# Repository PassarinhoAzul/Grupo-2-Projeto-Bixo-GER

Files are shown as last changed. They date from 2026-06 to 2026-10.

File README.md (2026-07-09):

# Projeto Bixo GER - Grupo 2 - Gênios da Bola

## Organizaçao das pastas:

``` 
|--- entrega1 (Entrega do Chassi)
         |--- modelos3d (modelos importados de fontes externas)
         |--- imagens (imagens usadas no README)
         |--- README (descrição da entrega)

|--- entrega2 (Entrega do Circuito)
         |--- código_teste (código para testar o esp32 e os motores)
         |--- esquemático (diagrama do circuito)
                    |---biblioteca_kicad (símbolos criados para o esquempatico)
                    |---arquivos_kicad (arquivo kicad do esquemático)
                    |---esquemático do projeto
         |--- imagens (imagens usadas no README)
         |--- README (descrição da entrega)
```

## Entregas
- Entrega 1: Chassi (17/06 às 18h00) 
- Entrega 2: Circuito (09/07 às 18h00)

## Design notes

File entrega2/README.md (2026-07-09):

# Entrega 02 - Projeto do Circuito

## Introdução

Primeiramente analisamos o datasheet de cada componente, para analisar qual seriam as conexões e placas a serem criadas para o projeto. Além disso, notamos a necessidade de alterar o suporte para o motor, já que ele não considerava a presença do encoder, que altera a altura do motor por causa da engrenagem. A partir disso, obtivemos alguns rascunhos. 

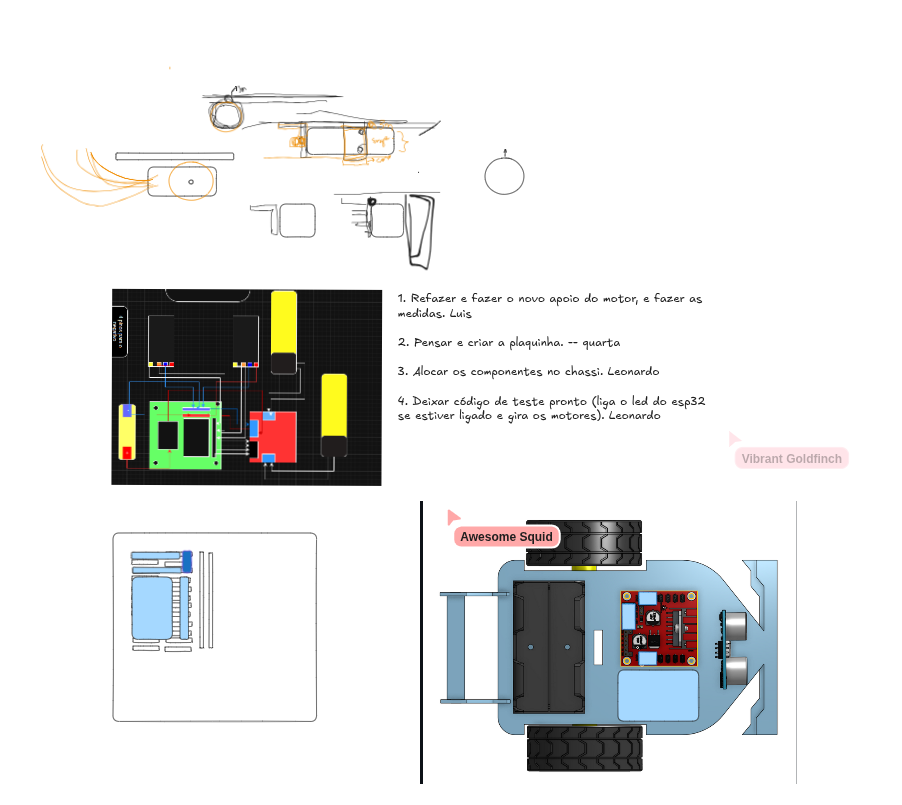
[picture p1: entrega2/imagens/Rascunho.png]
Rascunho


## Circuito

Fotos do esquemático:
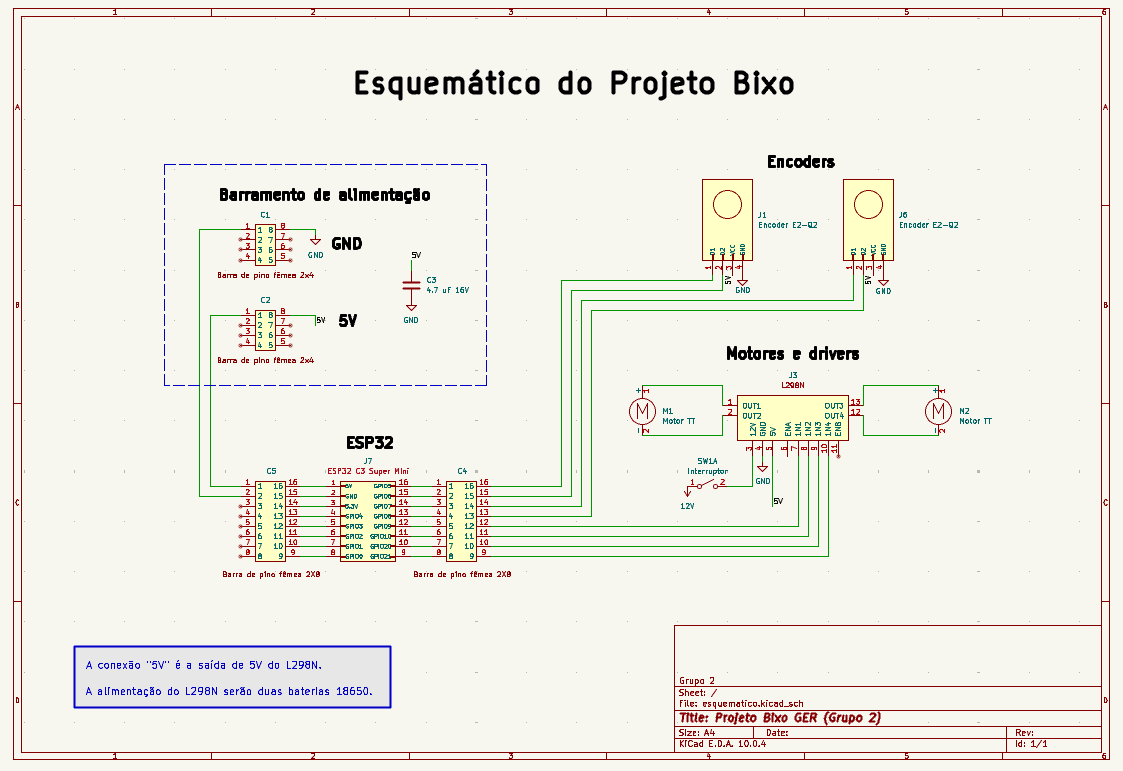
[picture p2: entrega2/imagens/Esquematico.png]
Esquemático


Fotos do circuito:
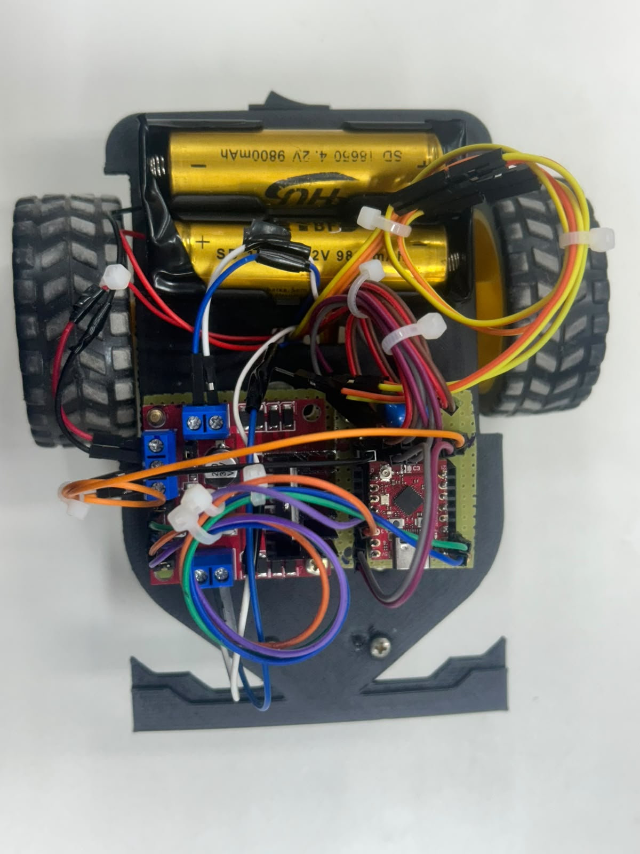
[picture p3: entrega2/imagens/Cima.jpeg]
Cima

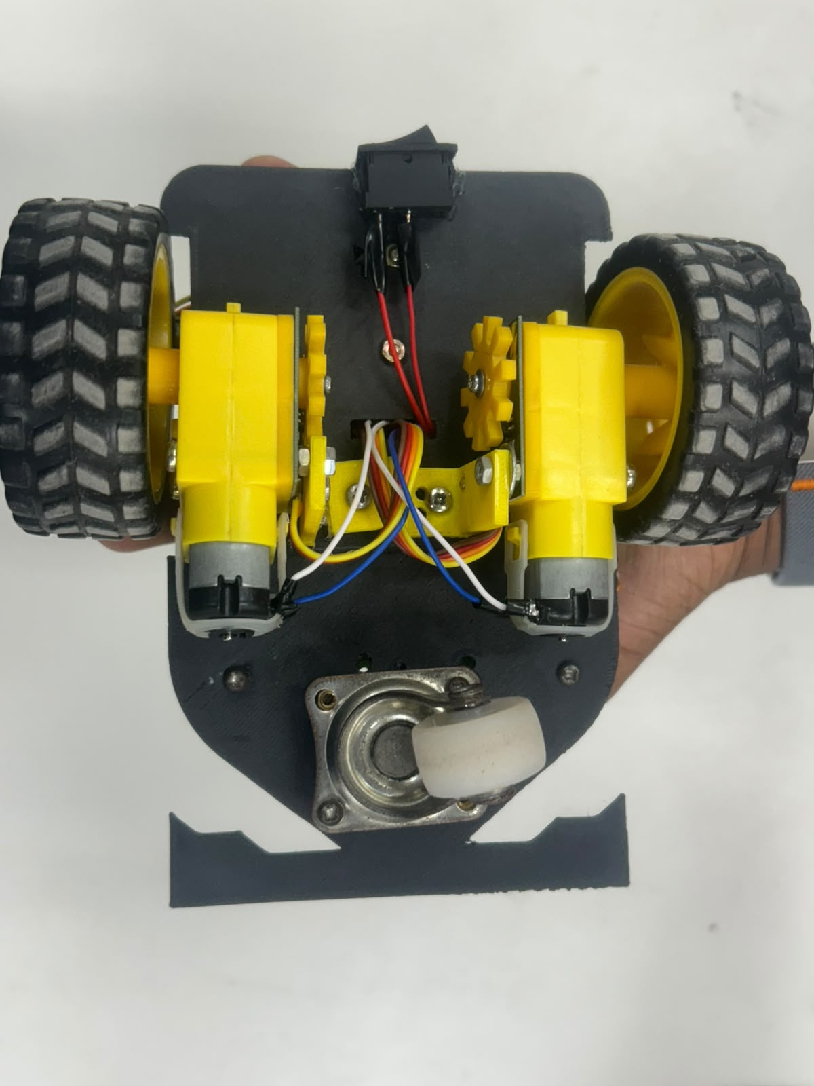
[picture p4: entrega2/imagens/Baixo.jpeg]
Baixo

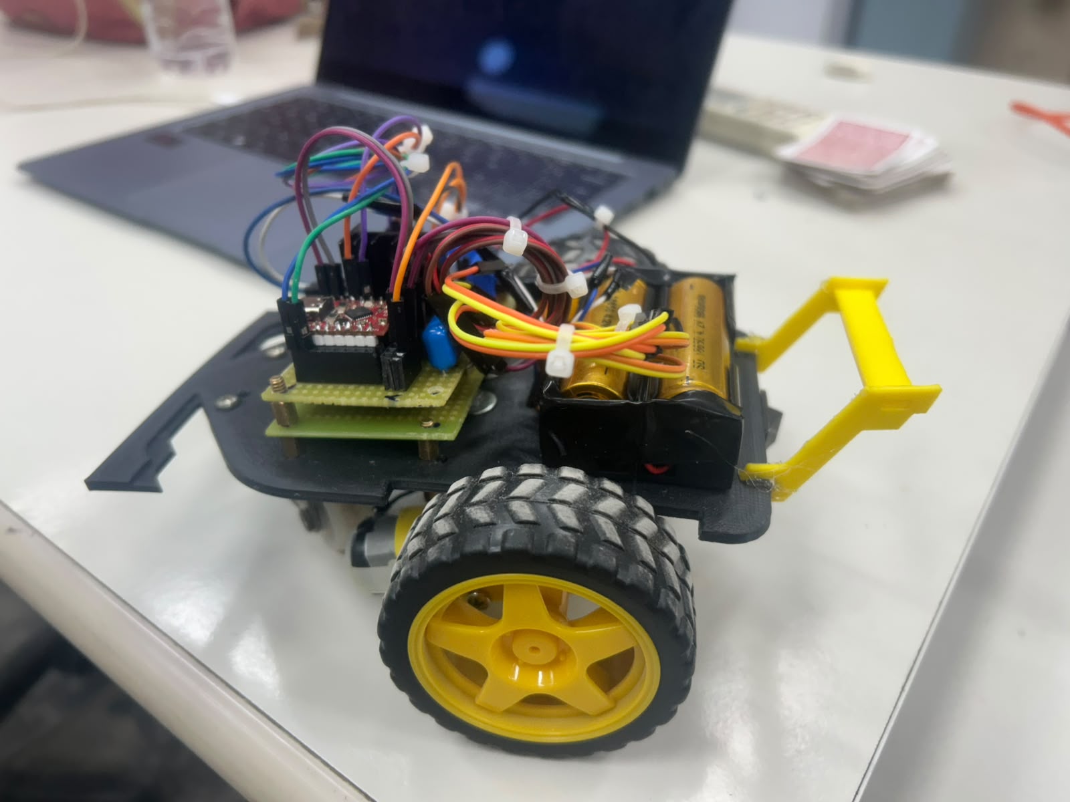
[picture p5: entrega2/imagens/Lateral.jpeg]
Lateral


***

### Alimentação:
A alimentação do circuito 'dividida em duas partes: 8V e 5V. 
- **8V:** alimentação da ponte H (L298N), feita através de duas pilhas 18650. As pilhas são colocadas em um suporte e a parte positiva desse conjunto é seccionado através de um interruptor que permite ligar ou desligar o robô.
- **5V:** alimentação do Esp32-C3 Super mini e dos Encoders. Ela advém do pino de +5V fornecido pela ponte H e do GND do robô, que são conectados em um barramento de alimentação (2x4 fêmea para cada). 

***

### Encaixe dos motores e encoders:
Para encaixar os motores e encoders, sofremos algumas dificuldades devido ao subdimensionamento dos suportes, já que não consideramos as engrenagens dos encoders. No entanto, conseguirmos resolver resolver esse problema utilizando uma sucata de impressão 3D, que possui uma altura adequada para ser encaixada entre os suportes e o chassi. Sendo assim, parafusamos esse conjunto. Outra dificuldade enfrentada foi a quebra de um dos suportes, que foi consertada utilizando um L em formato metálico, parafusando uma parte dele no suporte e a outra no chassi. Uma observação pertinente é que não foi possível imprimir novos suportes devido a falta de tempo e o não funcionamento da impressora no período.

***
### Encaixe das placas:
Para encaixar das placas, cortados uma placa ilhada em um tamanho adequado e montamos ela em cima do chassi, utilizando extensores, de tal forma que ela ficasse elevada. Isto é, pois haviam parafusos na parte inferior do espaço onde ficariam as placas. Após isso, montamos as placas no apoio com uso de porcas e parafusos, buscando fixar no mínimo 2 pontos de apoio. Além disso para o ESP32-C3 Super Mini, criamos uma placa com um barramento para todos os pinos do ESP, a fim de dar mias flexblidade no projeto, já que as conexões não permenantes permitem o teste de diferentes topologias.

***
### Procedimento:
Para os furos nas placas utilizamos a  furadeira de mão e de bancada, com pontas variando de 2mm a 4mm. Para fixar alguns componentes, como o aerofólio e o interruptor utilizamos cola quente. Para soldar os componentes, utilizamos a estação de solda, estanho e a fita de cobre. Por fim, para fixar os componentes, utilizamos porcas e parafusos, e para estruturas que necessitavam de muita pressão, inserimos aruelas entre as porca e parafusos para distribuir a pressão, não danificando o chassi.

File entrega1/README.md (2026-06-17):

# Entrega 01 - Projeto do Chassi

[Link do projeto no Onshape](https://cad.onshape.com/documents/1d821ed3f4f3fd0a0fea8587/w/eddb7fc55cb9cb03c94fa6ab/e/352dc380e6c08b1375bed07c)

## Procedimento 

A primeira coisa que fizemos foi medir os componentes que vamos utilizar no carrinho, sendo elas:
- ESP32-C3 Mini: 18mm x 22mm 4mm
- Sensor Ultrassônico HC-SR04: 45mm x 20mm x 15mm
- Ponte H L298N: 43mm x 43mm x 27
- Motor TT: 22mm x 70mm x 18mm
- Roda 65mm: 65mm x 27mm x 65mm
- Suporte para as pilhas: 75mm x 40mm x 20mm
- Roda Boba: 30mm x 30mm x ---

Após isso, fizemos uma reunião para debater as ideias iniciais para o modelo, buscando inspirações em carros de formula um e outros projetos semelhantes. O rascunho desenvolvido está representado na figura abaixo. 

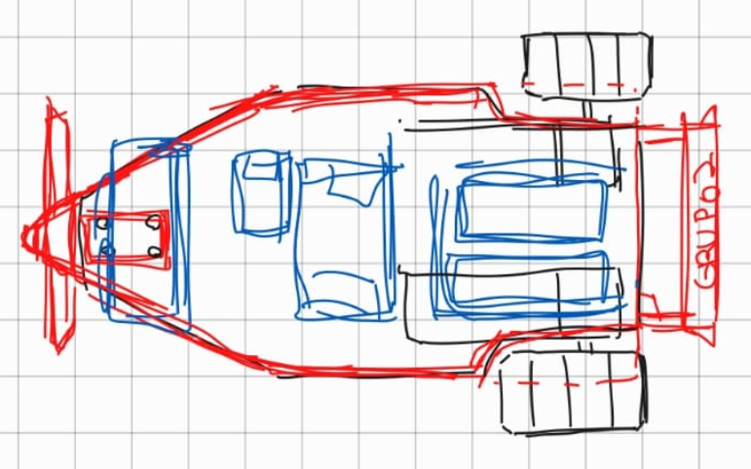
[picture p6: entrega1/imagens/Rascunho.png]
Rascunho


Durante a modelagem do projeto, baixamos modelos 3d dos componentes, obtidos no site ([3d Content Central](https://www.3dcontentcentral.com/Default.aspx)) para fazer testes com o modelo e verificar diferentes possibilidades para o posicionamento dos objetos no chassi.

## Modelo

Fotos do modelo com a simulação de componentes:

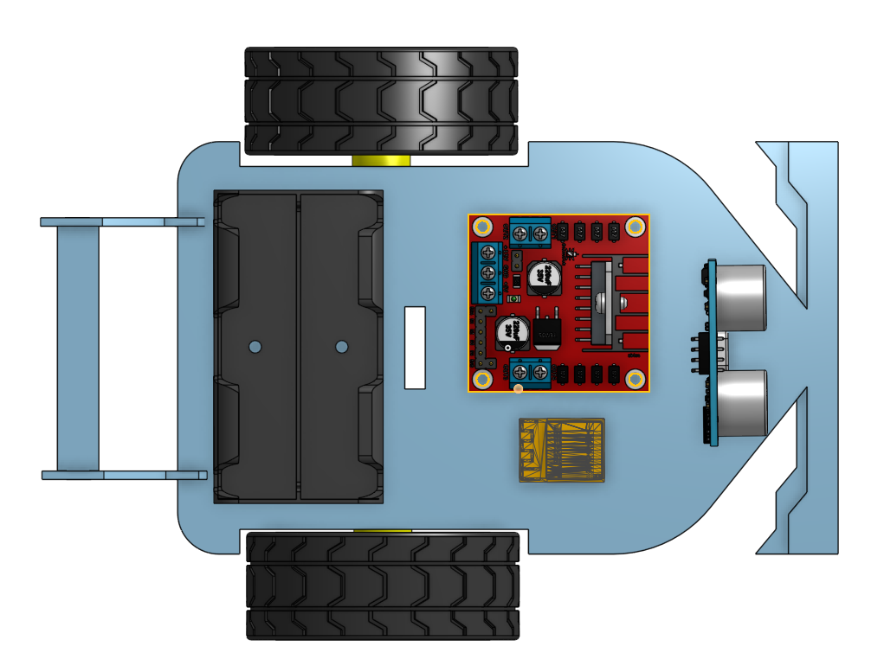
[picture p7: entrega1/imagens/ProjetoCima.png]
Cima

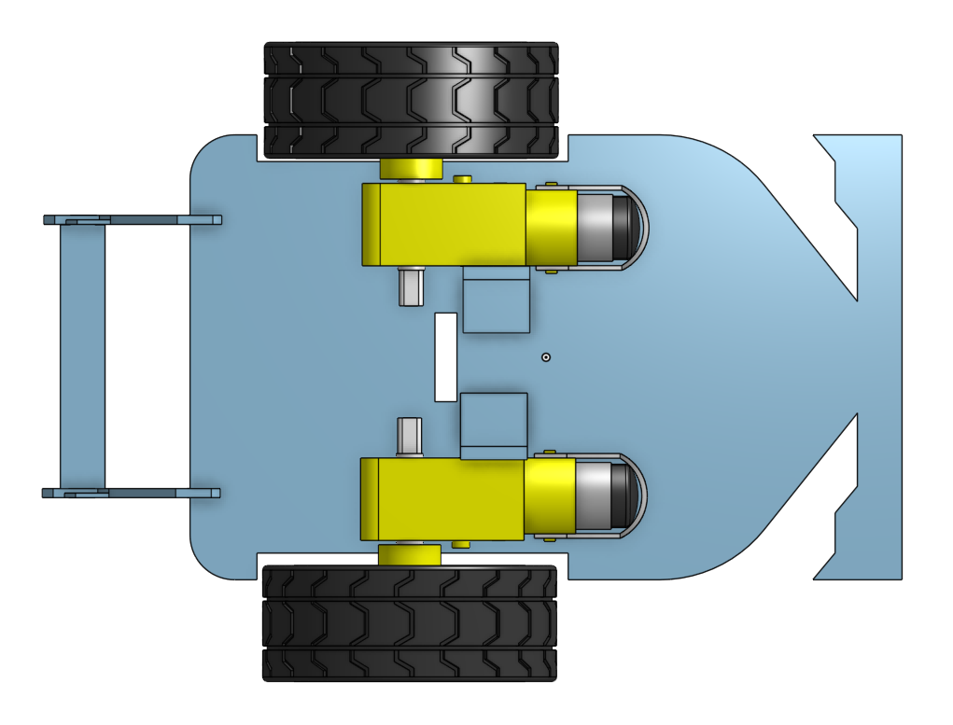
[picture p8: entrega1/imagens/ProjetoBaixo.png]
Baixo

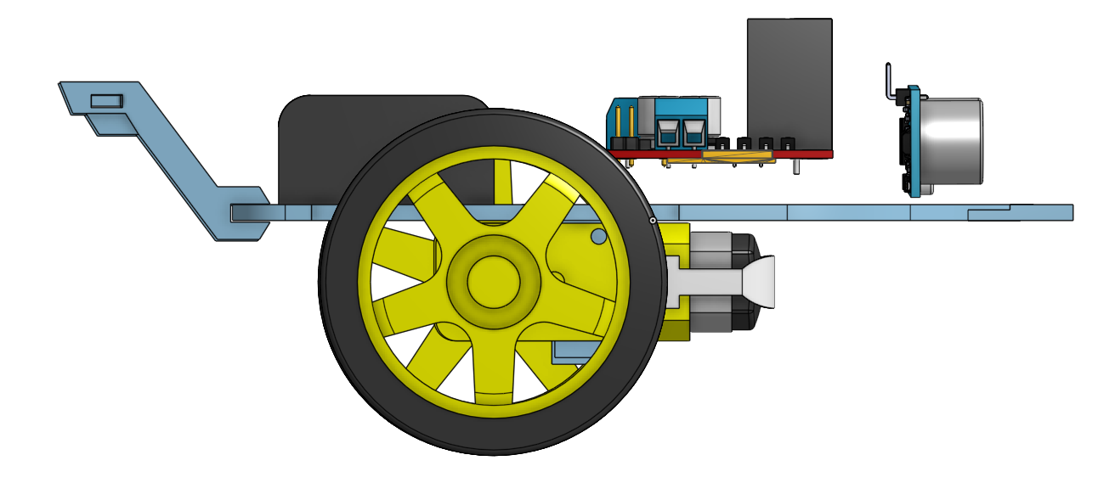
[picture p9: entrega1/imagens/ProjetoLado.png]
Lado


***

### Chassi:

As medidas do Chassi são de 100mm x 160m x 3m. Utilizamos essaas medidas baseada no encaixe dos componentes, com uma espessura adequada para suportar o peso de todos. Detalhando mais sobre o projeto, escolheu-se colocar os dois motores na parte de baixo e o restante dos componentes na parte de cima do chassi, reservando um espaço para um possível sensor ultrassônico. Além disso, o projeto possui um furo no centro para facilitar as conexões entre os componentes superiores e inferiores do carro. Por fim, os furos necessários para conectar os componentes ao chassi serão feitos utilizando uma furadeira, devido a facilidade e liberdade em compaação a criar furos diretamente no modelo das peças. Abaixo está uma imagem contendo o chassi.

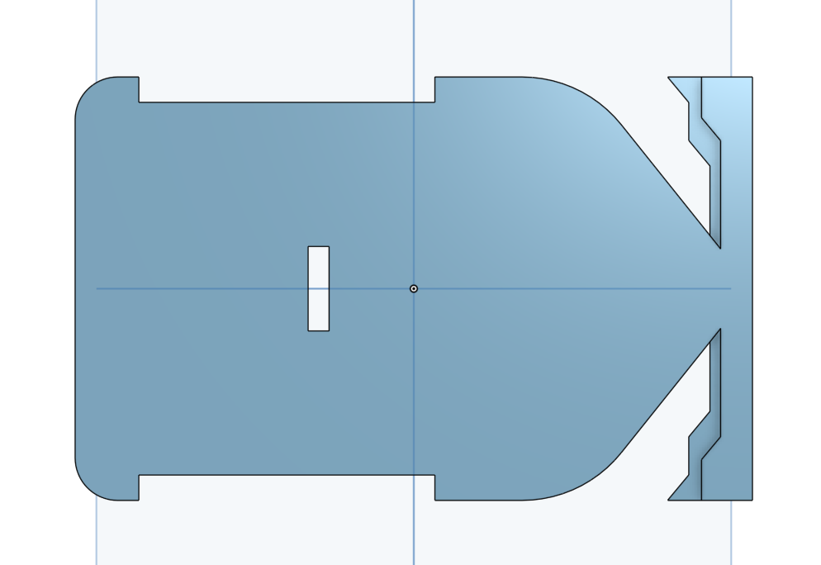
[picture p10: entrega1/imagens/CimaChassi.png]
Cima

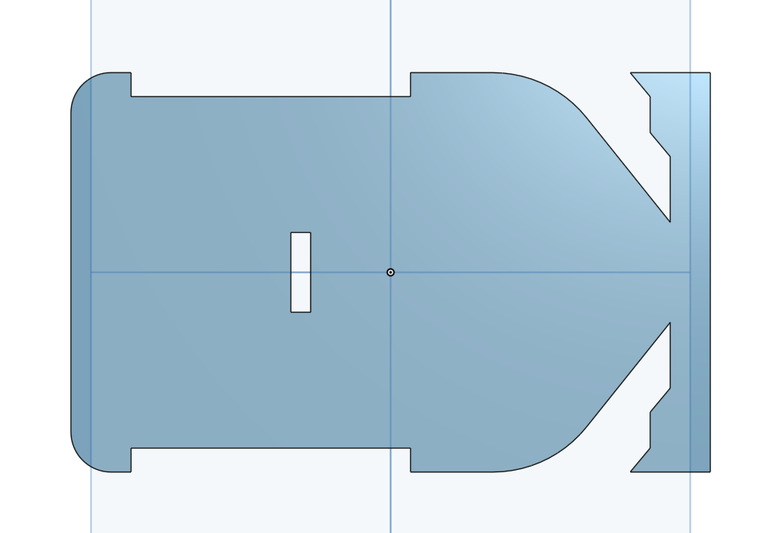
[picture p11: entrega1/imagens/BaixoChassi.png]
Baixo


***

### Aerofólio

O aerofólio é composto por duas partes: dois suportes laterais (30mm x 40mm x 3mm) e uma peça de encaixe horizontal (60mm x 10mm x 3mm). A tolerância para o encaixe de cada peça é de 0.5mm. Essa parte será encaixada e fortificada com cola no chassi. Abaixo está uma imagem contendo o aerofólio montado e cada peça individual. 

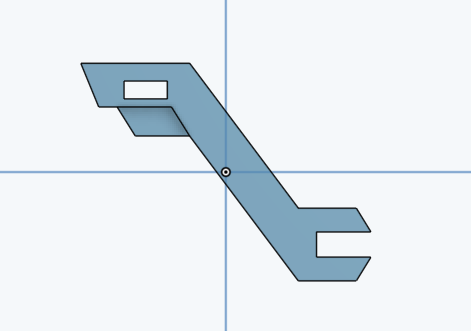
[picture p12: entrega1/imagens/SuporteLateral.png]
Suporte lateral

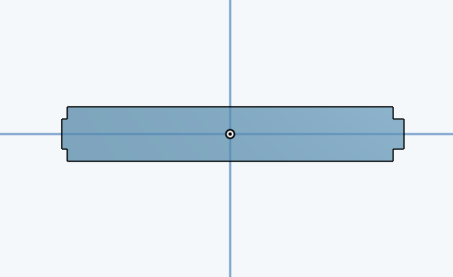
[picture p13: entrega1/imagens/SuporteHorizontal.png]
Suporte horizontal

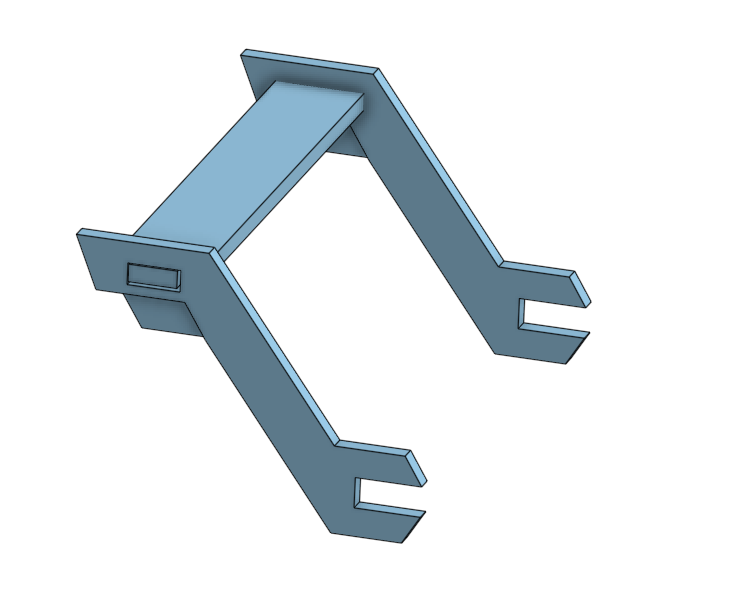
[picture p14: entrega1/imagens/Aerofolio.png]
Aerofólio montado


***

### Suportes:

Os suportes para os motores (localizados na parte debaixo do chassi) tem medida de (15mm x 15mm x 27mm). Os motores e os suporte serão parafusados (os furos serão feitos utilizando uma furadeira, devido a facilidade e liberdade em compaação a criar furos diretamente no modelo das peças) Abaixo está uma imagem do suporte. 

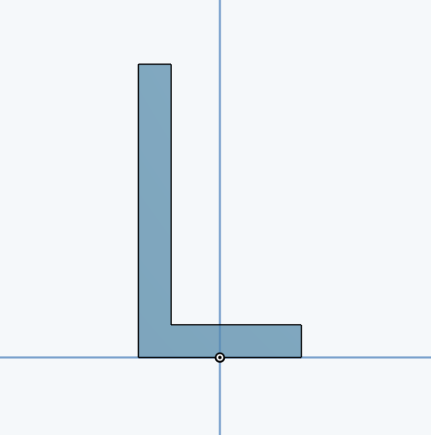
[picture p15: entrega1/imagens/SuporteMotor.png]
Suporte do motor


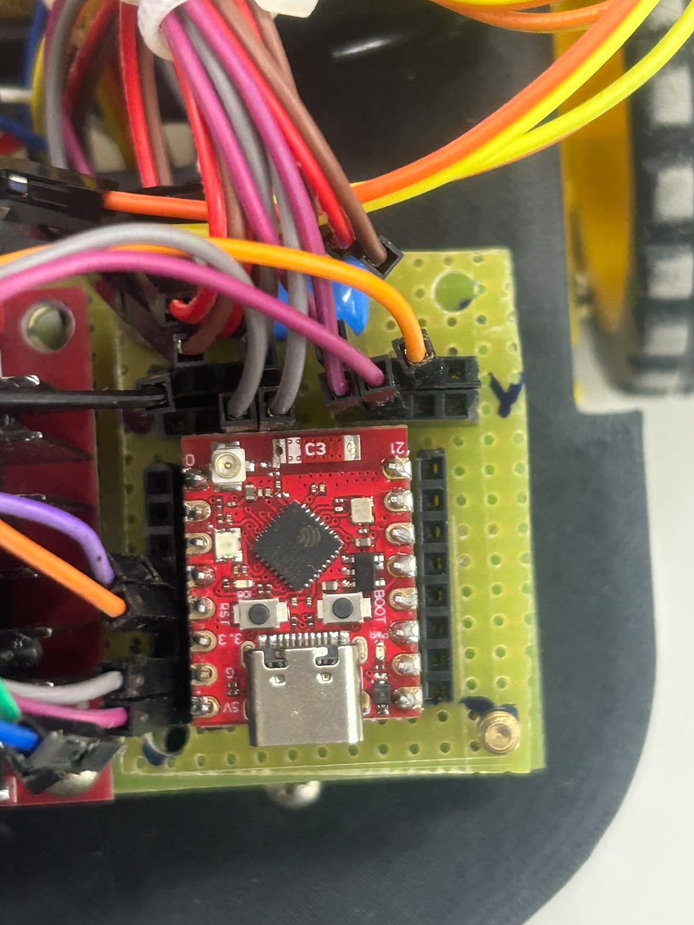
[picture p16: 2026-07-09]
entrega2/imagens/PBCs.jpeg

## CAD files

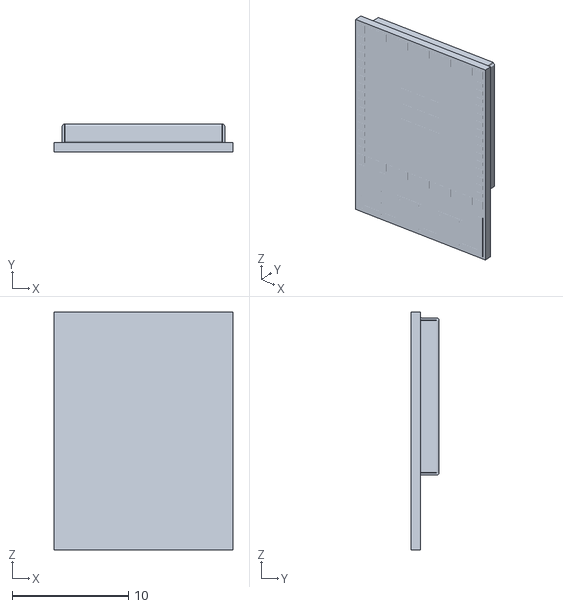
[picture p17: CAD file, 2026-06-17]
entrega1/modelos3d/User Library-ESP32-S3-MINI-1.STL
15.4 x 2.42 x 20.5

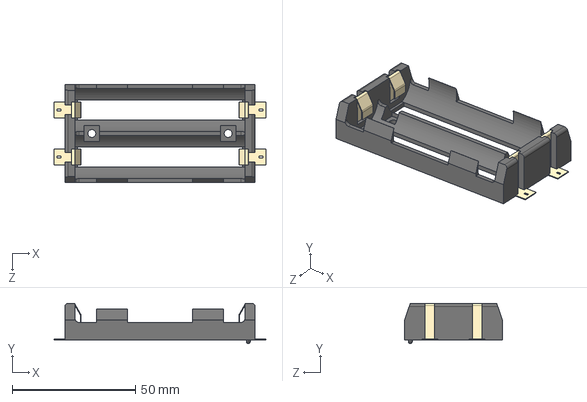
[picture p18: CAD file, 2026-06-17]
entrega1/modelos3d/User Library-Blossom 1048.STEP
86.0 x 16.4 x 39.8 mm
Blossom 1048-case
Blossom 1048P-spring x 4

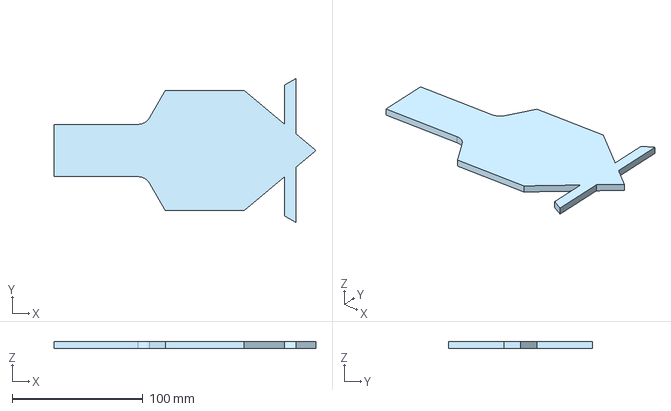
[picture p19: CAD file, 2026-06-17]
entrega1/modelos3d/Rhuan.step
200.0 x 110.0 x 5.00 mm

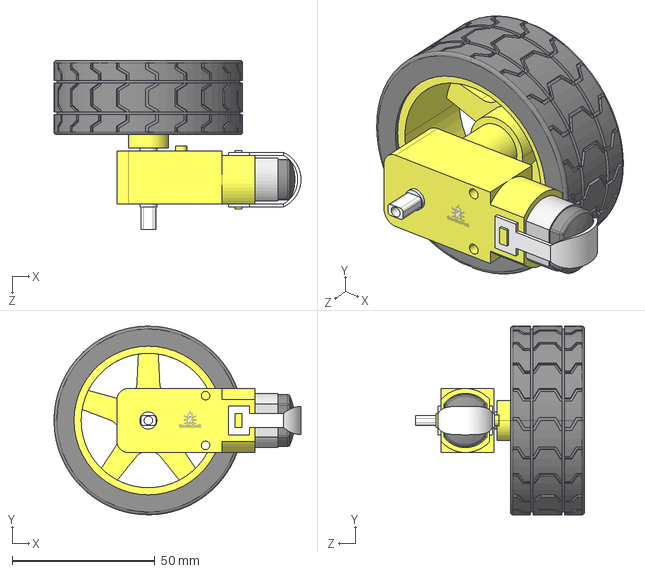
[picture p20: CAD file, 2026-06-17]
entrega1/modelos3d/User Library-SMART_ROBOT_WHEEL.STEP
86.4 x 66.0 x 59.2 mm
SMART_ROBOT_MOTOR
SMART_ROBOT_WHEEL

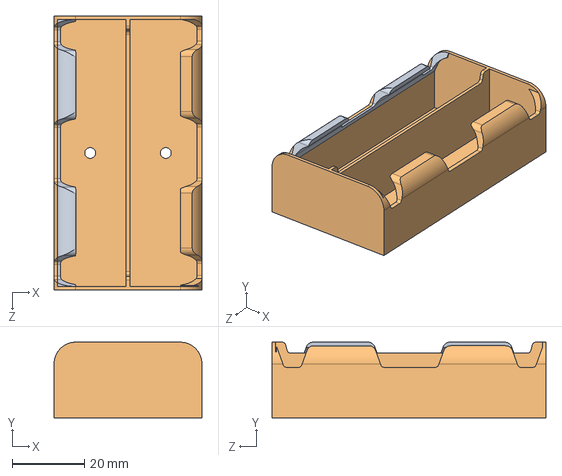
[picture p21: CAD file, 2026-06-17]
entrega1/modelos3d/User Library-18650 holder x2.STEP
41.0 x 21.0 x 76.0 mm

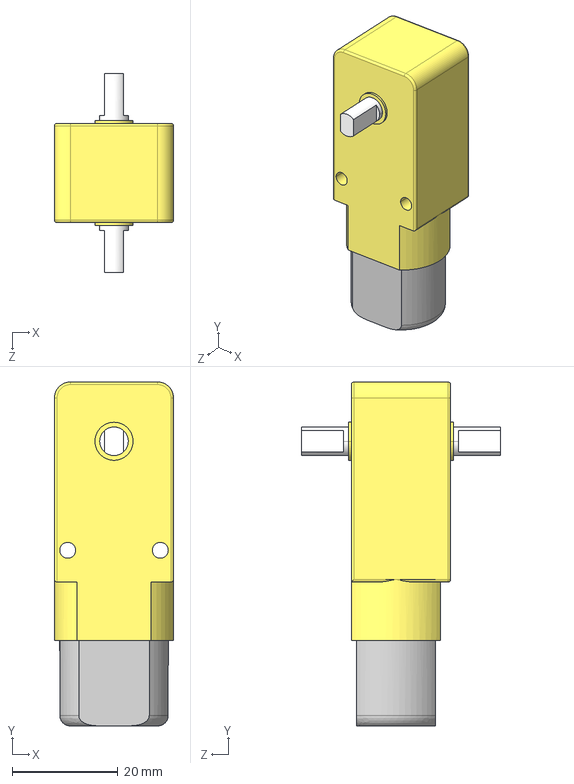
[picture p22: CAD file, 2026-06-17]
entrega1/modelos3d/User Library-dc_motor_5v_yellow.STEP
22.5 x 65.0 x 37.6 mm

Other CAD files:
entrega1/modelos3d/User Library-dc_motor_5v_yellow.DXF

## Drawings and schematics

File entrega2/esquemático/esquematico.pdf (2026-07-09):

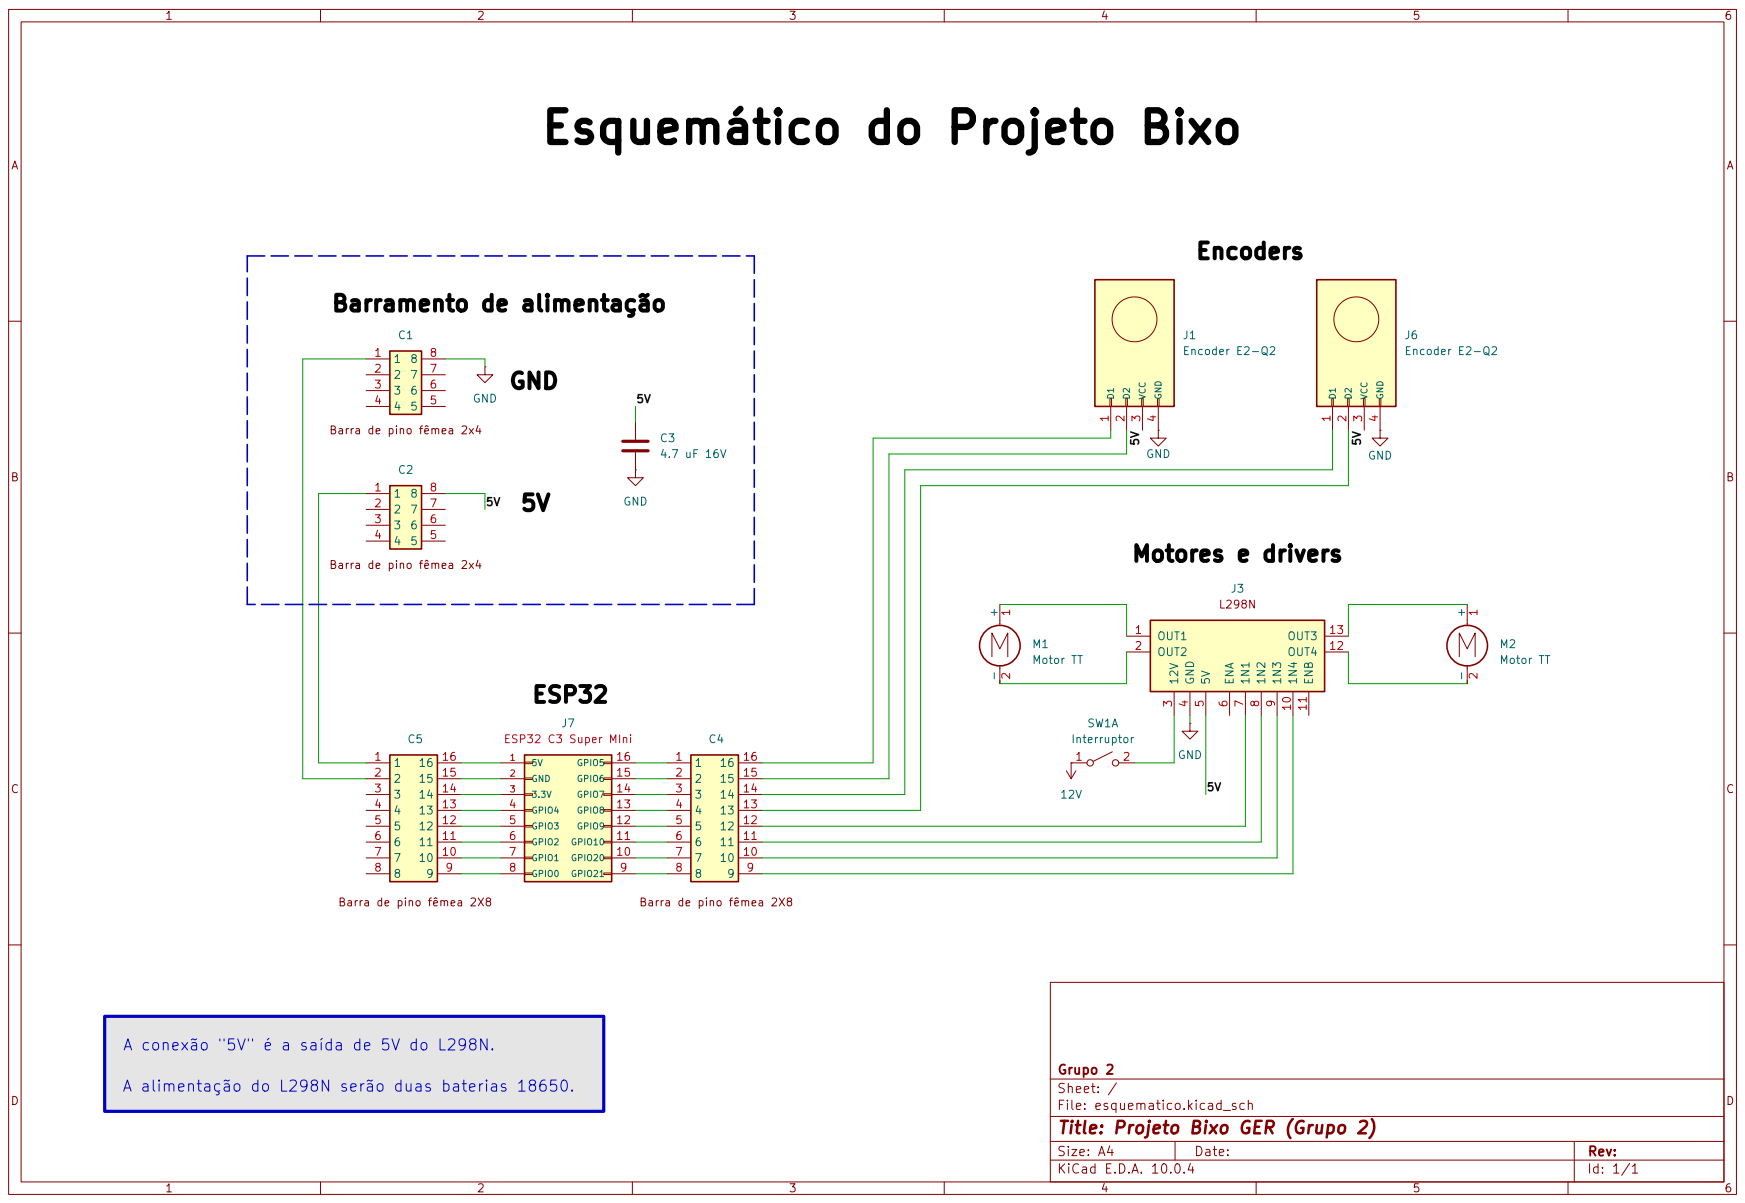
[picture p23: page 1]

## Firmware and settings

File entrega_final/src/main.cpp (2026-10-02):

#include <Arduino.h>

#define ENC_IN_ESQ_A 1//0
#define ENC_IN_ESQ_B 0//1
#define ENC_IN_DIR_A 3
#define ENC_IN_DIR_B 2

// Pinos da Ponte H 
#define MOT_ESQ_PWM 4
#define MOT_ESQ_IN1 6
#define MOT_ESQ_IN2 5
#define MOT_DIR_PWM 7
#define MOT_DIR_IN1 10
#define MOT_DIR_IN2 8

#define COMPRIMENTO_RODA 0.68 // cm

volatile long ticks_esq = 0;
volatile long ticks_dir = 0;

long ticks_ant_esq = ticks_esq;
long ticks_ant_dir = ticks_dir;

long delta_tempo = 0;

// Variaveis para garantir que o loop principal rode em frequencia fixa (Sem delay!)
long tempo_anterior = 0;
const int INTERVALO_AMOSTRAGEM_MS = 100; // Roda o controle a 20Hz

double kp = 2.0;
double ki = 0.5;
double kd = 1.0;

// Variáveis PID
double erroIntegral = 0;
double erroAnterior = 0;

struct Motor {
      // Pinos de controle (Ponte H)
      int pinPWM;
      int pinIN1;
      int pinIN2;

      // Variáveis de Velocidade
      double velocidadeDesejada;
      double velocidadeAtual;

      // Variáveis do PID
      double erroIntegral;
      double erroAnterior;

      int direcao;
};

Motor motorEsquerdo = {MOT_ESQ_PWM, MOT_ESQ_IN1, MOT_ESQ_IN2, 0.0, 0.0, 0.0, 0.0, 0};
Motor motorDireito  = {MOT_DIR_PWM, MOT_DIR_IN1, MOT_DIR_IN2, 0.0, 0.0, 0.0, 0.0, 0};

// ISR do Encoder Esquerdo
void IRAM_ATTR isr_encoder_esq() {
  /*if (digitalRead(ENC_IN_ESQ_B) == HIGH) {
    ticks_esq++;
  } else {
    ticks_esq--;
  }*/
 ticks_esq++;
}

// ISR do Encoder Direito
void IRAM_ATTR isr_encoder_dir() {
  /*if (digitalRead(ENC_IN_DIR_B) == HIGH) {
    ticks_dir++;
  } else {
    ticks_dir--;
  }*/
 ticks_dir++;
}


void calcula_odometria() {
  // O resgate de variaveis volatile precisa ser rapido. 
  // Desligamos as interrupcoes por um microssegundo para copiar os valores e nao corromper os dados.
  noInterrupts();
  long ticks_atuais_esq = ticks_esq;
  long ticks_atuais_dir = ticks_dir;
  
  interrupts();
  
  // Quantidade de ticks no intervalo delta de tempo
  int delta_ticks_esq = ticks_atuais_esq - ticks_ant_esq;
  int delta_ticks_dir = ticks_atuais_dir - ticks_ant_dir;


  // Tick por seg
  // Calcular para cada roda
  double vel_esq_ticks = ((double)delta_ticks_esq / ((double)delta_tempo / 1000));
  double vel_dir_ticks = ((double)delta_ticks_dir / ((double)delta_tempo / 1000));


  // Velocidade angular
  // 1 tick /10
  double rot_dir = vel_dir_ticks / 10;
  double rot_esq = vel_esq_ticks / 10;

  motorEsquerdo.velocidadeAtual = rot_esq * COMPRIMENTO_RODA * motorEsquerdo.direcao;
  motorDireito.velocidadeAtual = rot_dir * COMPRIMENTO_RODA * motorDireito.direcao;

  Serial.print("Delta ticks (esq) (dir) = ");
  Serial.print(delta_ticks_esq);
  Serial.print("    ");
  Serial.println(delta_ticks_dir);

  Serial.print("Velocidade Linear (esq) (dir) = ");
  Serial.print(motorEsquerdo.velocidadeAtual);
  Serial.print("    ");
  Serial.println(motorDireito.velocidadeAtual);

  ticks_ant_esq = ticks_atuais_esq;
  ticks_ant_dir = ticks_atuais_dir;

}

void calcularPIDMotor(Motor *motor)
{
      if (delta_tempo <= 0) return;

      // Cálculo do Erro
      double erro = motor->velocidadeDesejada - motor->velocidadeAtual;

      // Termo Integral com Anti-Windup
      motor->erroIntegral += erro * (delta_tempo / 1000.0);
      motor->erroIntegral = constrain(motor->erroIntegral, -100.0, 100.0);

      // Termo Derivativo
      double erroDerivativo = (erro - motor->erroAnterior) / (delta_tempo / 1000.0);

      // Sinal de Saída usando os Kps globais
      double sinalSaida = (kp * erro) + (ki * motor->erroIntegral) + (kd * erroDerivativo);

      // Tratamento de parada
      if (motor->velocidadeDesejada == 0)
      {
      sinalSaida = 0;
      motor->erroIntegral = 0;
      }

      // Direção dos pinos da Ponte H
      if (sinalSaida > 0)
      {
        motor->direcao = 1;
      digitalWrite(motor->pinIN1, HIGH);
      digitalWrite(motor->pinIN2, LOW);
      }
      else if (sinalSaida < 0)
      {
        motor->direcao = -1;
      digitalWrite(motor->pinIN1, LOW);
      digitalWrite(motor->pinIN2, HIGH);
      }
      else
      {
      digitalWrite(motor->pinIN1, LOW);
      digitalWrite(motor->pinIN2, LOW);
      }

      // Cálculo do PWM com Offset para atrito estático
      int pwm = abs((int)sinalSaida);
      if (motor->velocidadeDesejada != 0 && pwm > 0)
      {
      pwm = pwm + 30; // Mínimo PWM para dar a partida
      }
      pwm = constrain(pwm, 0, 255);

      // Enviar PWM para a Ponte H
      analogWrite(motor->pinPWM, pwm);

      // Atualizar erro anterior do motor
      motor->erroAnterior = erro;
}

void setup() {
  Serial.begin(9600);
  
  // Encoders
  pinMode(ENC_IN_ESQ_A, INPUT_PULLUP);
  pinMode(ENC_IN_ESQ_B, INPUT_PULLUP);
  pinMode(ENC_IN_DIR_A, INPUT_PULLUP);
  pinMode(ENC_IN_DIR_B, INPUT_PULLUP);
  attachInterrupt(digitalPinToInterrupt(ENC_IN_ESQ_A), isr_encoder_esq, RISING);
  attachInterrupt(digitalPinToInterrupt(ENC_IN_DIR_A), isr_encoder_dir, RISING);

  // Motores
  pinMode(motorEsquerdo.pinPWM, OUTPUT);
  pinMode(motorEsquerdo.pinIN1, OUTPUT);
  pinMode(motorEsquerdo.pinIN2, OUTPUT);
  pinMode(motorDireito.pinPWM, OUTPUT);
  pinMode(motorDireito.pinIN1, OUTPUT);
  pinMode(motorDireito.pinIN2, OUTPUT);

  motorDireito.velocidadeDesejada = 0;
  motorEsquerdo.velocidadeDesejada = 0;

  
  Serial.println("Sistema Iniciado. Aguardando inicio dos ciclos de controle...");
}

void loop() {
  unsigned long tempo_atual = millis();
  delta_tempo = tempo_atual - tempo_anterior;

  if (delta_tempo >= INTERVALO_AMOSTRAGEM_MS) {
    calcula_odometria();
    calcularPIDMotor(&motorDireito);
    calcularPIDMotor(&motorEsquerdo);
    tempo_anterior = tempo_atual;
  }

  if (tempo_atual > 2000 && tempo_atual < 7000)
  {
    motorDireito.velocidadeDesejada = 40;
    motorEsquerdo.velocidadeDesejada = 40;
  }

  if (tempo_atual > 7000)
  {
    motorDireito.velocidadeDesejada = 0;
    motorEsquerdo.velocidadeDesejada = 0;
  }
}

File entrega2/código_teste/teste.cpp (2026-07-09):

#include <Arduino.h>

// ===========================
// Definição dos pinos
// ===========================

// Motor esquerdo
const int IN1 = 5;
const int IN2 = 6;

// Motor direito
const int IN3 = 3;
const int IN4 = 4;

void setup()
{
    // Configura os pinos como saída
    pinMode(IN1, OUTPUT);
    pinMode(IN2, OUTPUT);

    pinMode(IN3, OUTPUT);
    pinMode(IN4, OUTPUT);

    // Garante que os motores começam desligados
    digitalWrite(IN1, LOW);
    digitalWrite(IN2, LOW);

    digitalWrite(IN3, LOW);
    digitalWrite(IN4, LOW);


  
}

void loop()
{
    // Frente
    digitalWrite(IN1, HIGH);
    digitalWrite(IN2, LOW);

    digitalWrite(IN3, HIGH);
    digitalWrite(IN4, LOW);

    delay(3000);

    // Trás
    digitalWrite(IN1, LOW);
    digitalWrite(IN2, HIGH);

    digitalWrite(IN3, LOW);
    digitalWrite(IN4, HIGH);

    delay(3000);
}

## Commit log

2026-06-17 Adicionei os modelos 3d dos commponentes.
    [Rhuan.step, User Library-18650 holder x2.STEP, User Library-Blossom 1048.STEP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]
2026-06-17 Adicionei o README
    [Rhuan.step, User Library-18650 holder x2.STEP, User Library-Blossom 1048.STEP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]
2026-07-01 Adicionei o esquematico.
    [esquematico.kicad_pcb, esquematico.kicad_sch]
2026-07-09 Atualizei o esquemático e o ReadME.
    [esquematico.kicad_sch]
2026-08-28 Fazendo o calc da velocidade: tick/s
2026-09-03 calculo_odometria completo; calculo de direcao da roda
2026-09-03 velocidades dando 0 e -1
2026-09-29 Odometria quase completa: falta a direcao
2026-10-02 Codigo PID completo v1: struct MOTOR adicionada
2026-10-02 Atualizando a main com o PID completo
